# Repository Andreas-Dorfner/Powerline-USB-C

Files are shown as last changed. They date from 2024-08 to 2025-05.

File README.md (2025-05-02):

 # Powerline-USB-C
Powerline is a small 3HP Front Entry USB C Eurorack power supply.
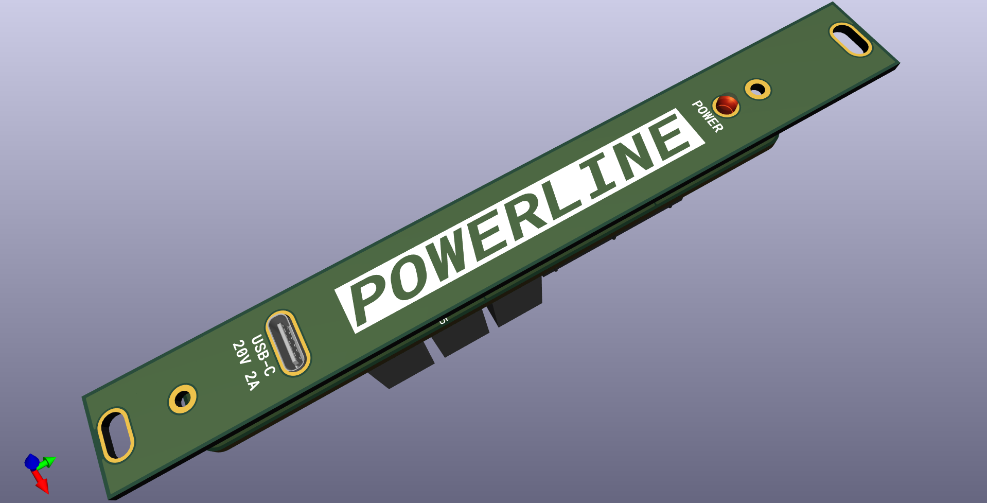
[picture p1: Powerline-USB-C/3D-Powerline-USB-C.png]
3D render

## Repository Layout
The Frontpanel and main PCB have a Kicad project with footprint and symbol libraries.
The main PCB also includes a 3D render of the Frontpanel as a Footprint
## Specs
- 12V 1000mA
- -12V 300mA
- 5V 1000mA
## Features
Powerline uses the cheap and readily available CH224k IC to get 20V over USB-C PD. The power brick should supply at least 2A of current at that voltage (40W Charger and above should be fine).
The 20V then gets regulated to a dual +/-12V and 5V supply by two N7812-1C and an N7805-1C and can be accessed by one 16-pin Power header. You can also omit the 5V rail and solder a 10pin header if none of your modules need 5V.
Powerline uses a single LED powered by the 12V rail to indicate power.
The PCBs are designed to jlcpcbs 2 Layer design capabilities to be compatible with most cheap PCB services.
## Parts List
The only difficult-to-source parts are the USB-C connector and regulator ICs. I got both from Digikey.
I also recommend sourcing the CH224k from a reputable supplier like LCSC to avoid broken parts.
You also need two M2 5mm standoffs and 4 M2 screws that fit the standoffs (max. 4mm) to assemble the Module.
Schematic
|Part Number|Value|Information|
|---|---|---|
|C1, C8|0805 1uF 50V X7R|Decoupling Capacitors|
|C2, C4, C6|1210 10uF 50V X7R|Input Cap for the regulator|
|C3, C5, C7|1210 22uF 25V X7R|Output cap for the regulator|
|D1|3mm LED|3mm radial LED with a nice color|
|J1|MC-802YC-H105|Female USB-C connector|
|J2|Power header|A 02x08 2.54mm pin spacing vertical through hole pin header|
|L1|1210 10uH|Look out for a rated current of above 600mA|
|R1|0603 5k1|Current limiting resistor for the LED: if it's too bright, pick a higher resistance|
|R2|0604 10k|VBUS sense resistor|
|U1|CH224K|The PD trigger IC|
|U2, U3|N7912-1C|+/-12V regulators|
|U4|N7805-1C|5V regulator|
|U5|HT7533-1|3.3V regulator|
|Standoffs|m2 5-7.5mm|You need 2 Standoffs and 4 screws to mount the Module to its front plate
## Build Guide
The PCB doesn't include any Thermal reliefs so that soldering can be tricky with a weak iron or small tip. I did everything with a 60W and 4mm Bevel Tip on a TS100 with extra Flux. You do not need additional equipment as the CH224K is solderable from the bottom. I used 7.5mm Standoffs, which protects the USB-C connector nicely. I would recommend soldering the USB-C connector last.

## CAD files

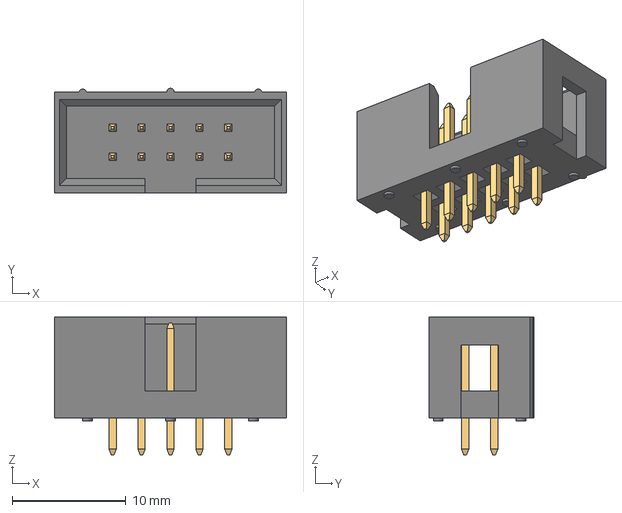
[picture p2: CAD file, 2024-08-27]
Powerline-USB-C/3D Models/Keye_10pin_Powerheader.stp
20.4 x 9.18 x 12.1 mm
6120xx21621_PIN x 10

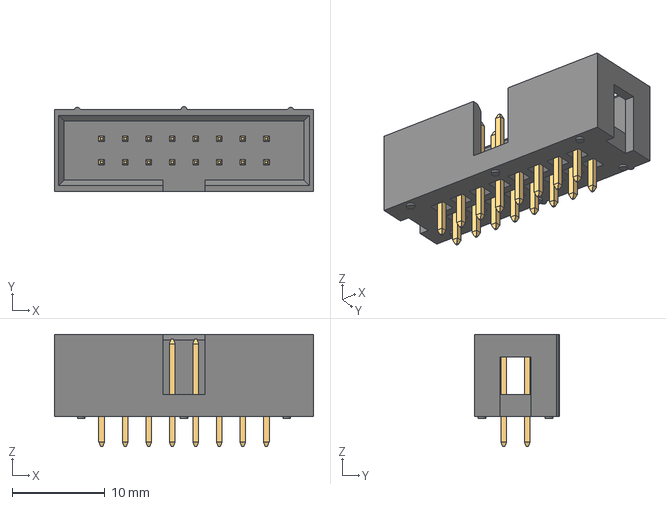
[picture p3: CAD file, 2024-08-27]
Powerline-USB-C/3D Models/Keyed_16pin_Powerheader.stp
28.0 x 9.18 x 12.1 mm
6120xx21621_PIN x 16

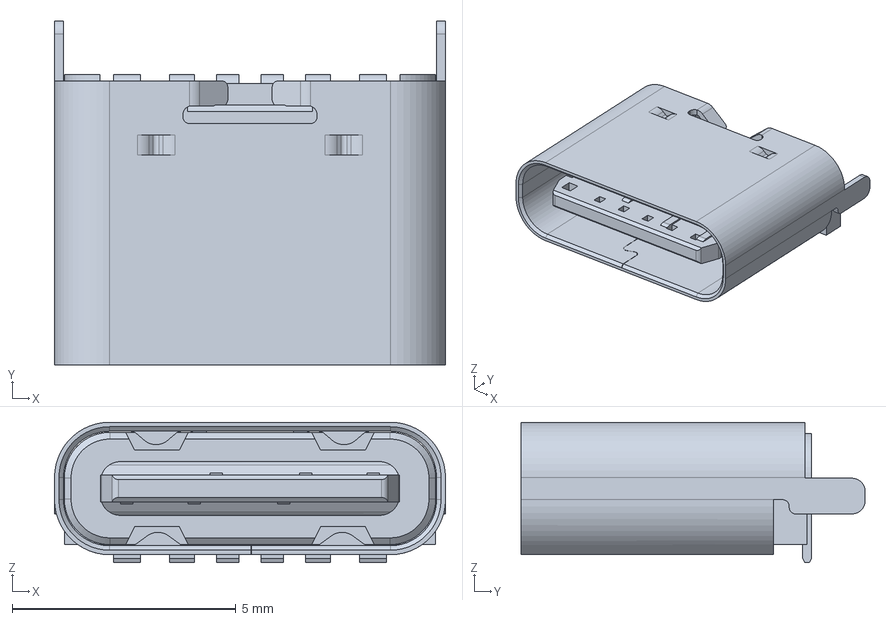
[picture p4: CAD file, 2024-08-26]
Powerline-USB-C/3D Models/USB-C.stp
8.74 x 7.70 x 3.14 mm

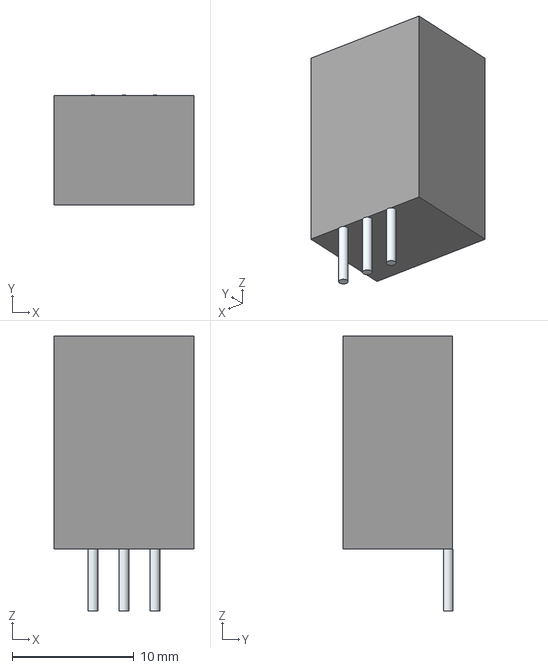
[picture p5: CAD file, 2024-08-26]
Powerline-USB-C/3D Models/N7803-1C.stp
11.5 x 9.08 x 22.6 mm
Leads

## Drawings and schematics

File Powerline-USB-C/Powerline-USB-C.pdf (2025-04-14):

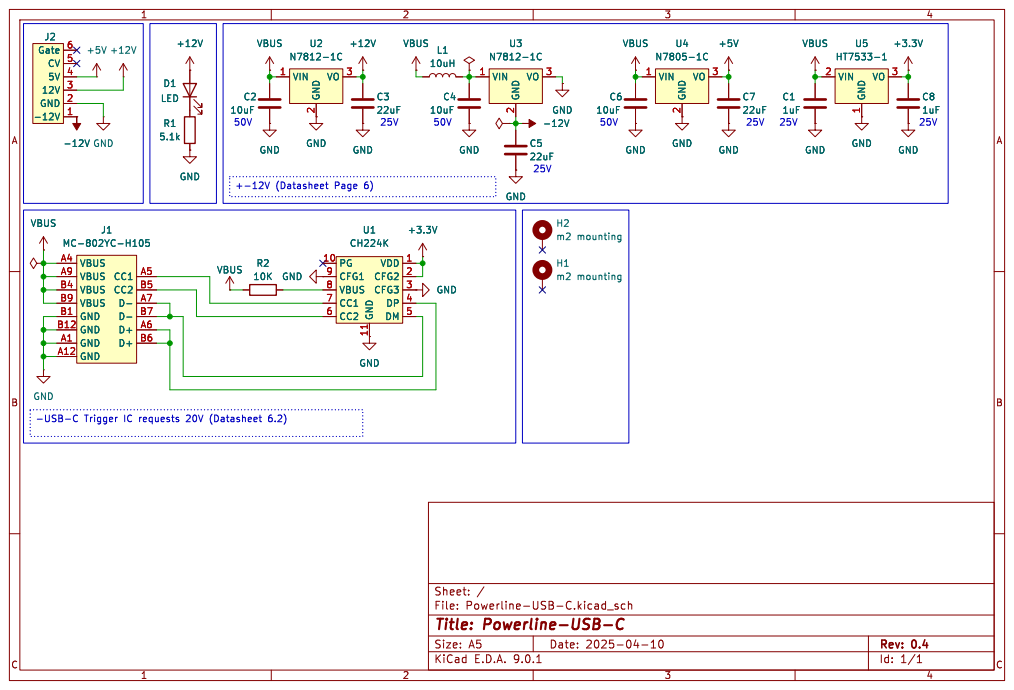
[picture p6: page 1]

2 VO 3 VBUS GND GND

Id: 1/1 Title: Powerline-USB-C

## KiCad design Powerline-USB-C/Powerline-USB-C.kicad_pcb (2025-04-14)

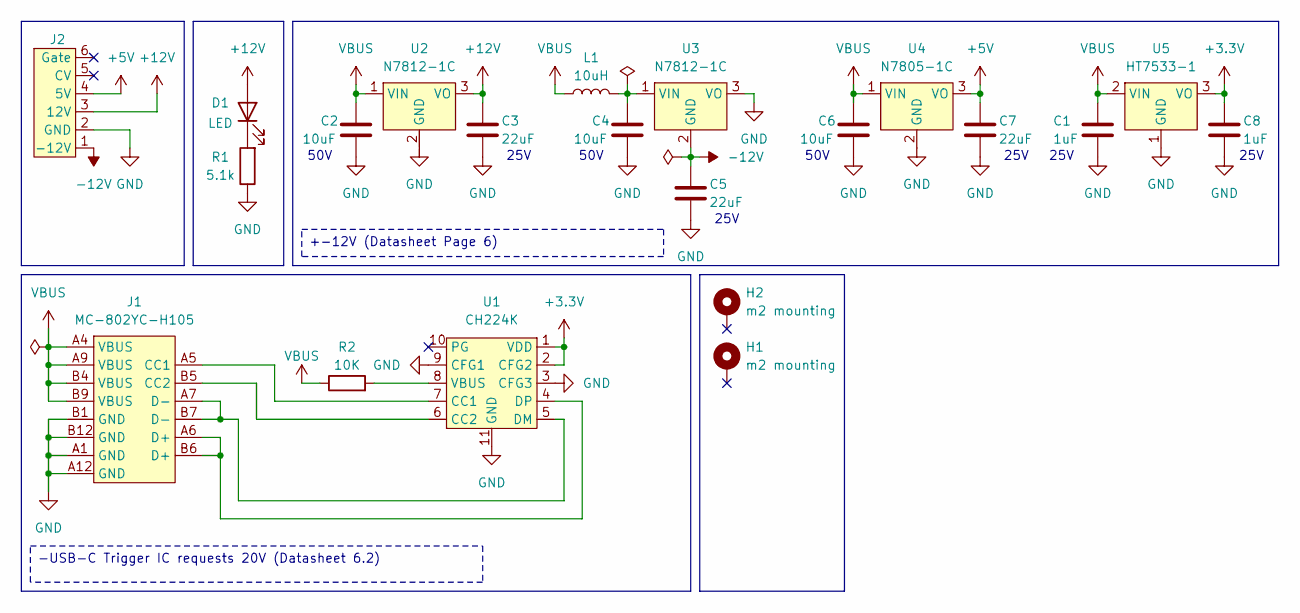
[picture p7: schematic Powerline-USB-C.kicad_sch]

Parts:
C1, C8: 1uF; C_0805_2012Metric
C2, C4, C6: 10uF; C_1210_3225Metric
C3, C5, C7: 22uF; C_1210_3225Metric
D1: LED; LED_D3.0mm
H1, H2: m2 mounting; MountingHole_2.2mm_M2_DIN965_Pad
J1: MC-802YC-H105; USB-C
J2: Keyed_16pin_Powerheader
L1: 10uH; L_1210_3225Metric
R1: 5.1k; C_0603_1608Metric
R2: 10K; R_0603_1608Metric
U1: CH224K; CH224k
U2, U3: N7812-1C
U4: N7805-1C; N7812-1C
U5: HT7533-1

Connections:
+3.3V: C8.1, U1.1 (VDD), U1.2 (CFG2), U5.3 (VO)
+5V: C7.1, J2.4 (5V), U4.3 (VO)
+12V: C3.1, D1.2 (A), J2.3 (12V), U2.3 (VO)
-12V: C5.1, J2.1 (-12V), U3.2 (GND)
GND: C1.2, C2.2, C3.2, C4.2, C5.2, C6.2, C7.2, C8.2, J1.A1 (GND), J1.A12 (GND), J1.B1 (GND), J1.B12 (GND), J2.2 (GND), R1.1, U1.3 (CFG3), U1.9 (CFG1), U1.11 (GND), U2.2 (GND), U3.3 (VO), U4.2 (GND), U5.1 (GND)
unnamed: D1.1 (K), R1.2
unnamed: J1.A5 (CC1), U1.7 (CC1)
unnamed: J1.B5 (CC2), U1.6 (CC2)
unnamed: J1.A7 (D-), J1.B7 (D-), U1.5 (DM)
unnamed: J1.A6 (D+), J1.B6 (D+), U1.4 (DP)
unnamed: R2.2, U1.8 (VBUS)
unnamed: C4.1, L1.2, U3.1 (VIN)
VBUS: C1.1, C2.1, C6.1, J1.A4 (VBUS), J1.A9 (VBUS), J1.B4 (VBUS), J1.B9 (VBUS), L1.1, R2.1, U2.1 (VIN), U4.1 (VIN), U5.2 (VIN)

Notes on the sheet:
25V
50V
-USB-C Trigger IC requests 20V (Datasheet 6.2)
+-12V (Datasheet Page 6)

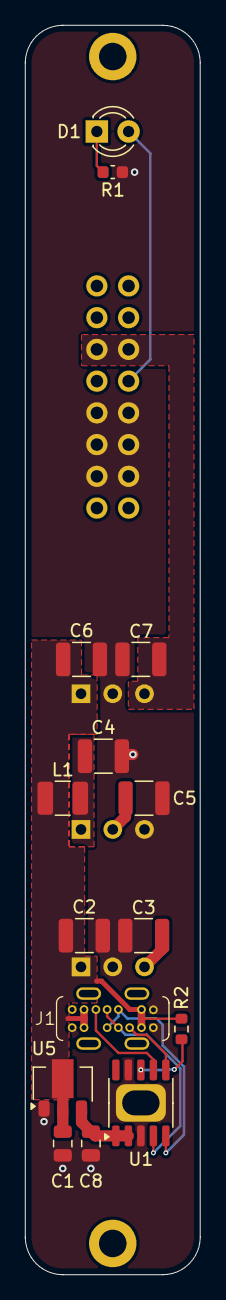
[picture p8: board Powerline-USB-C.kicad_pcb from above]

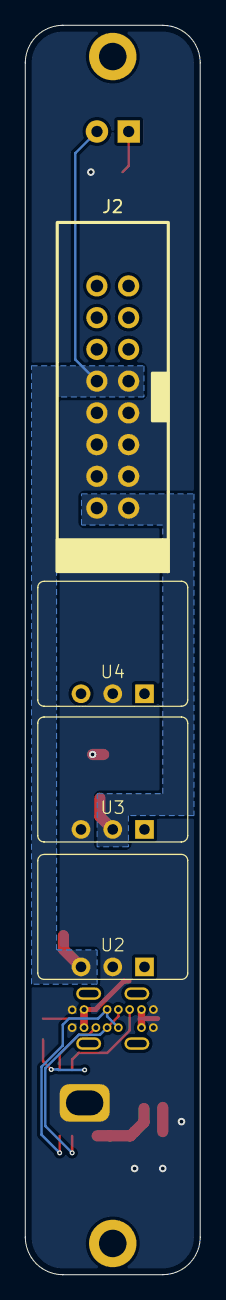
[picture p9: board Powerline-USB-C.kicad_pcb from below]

Board: 2 copper layers, 14.0 x 100.0 mm, 21 parts (4 on the bottom side), 13 nets.

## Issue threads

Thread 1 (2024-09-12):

wierd voltages

KeLaiFu, 2024-09-12:
I've built one of these and I am getting -12 and 5v on the header, but 4.9v on the +12. I checked the power coming from pin 1 on the IC, and its 1.3v (?) but 4.6v on the VBUS pin on the other side of R1.

I'm using meanwell DC blocks and ICs from LCSC and with such a small BOM, I am at a loss...

Any ideas?

Andreas-Dorfner, 2024-09-12:
I'm sorry your module isn't working as it should. The good thing is the voltages you measured mean that most of the module is ready to go. As for the rest:
The first thing to check is if the USB-C brick you are using supports 20V and the PD protocol.
If that is the case, that would indicate a problem with the USB-C trigger Circuit around the CH224K.
I haven't built the USB-C version of this module jet, so I can't confirm if the problem is in the schematic or your particular build. However, as you are using genuine parts, I highly suspect that the default implementation in the CH224k datasheet is faulty. As a quick fix, it will work for now if you supply the module with 20V through the USB-C port with a rigged cable (like a USB-C trigger cable) or a barrel Jack.
I will look through the USB-C trigger section again and update you if I find an error.

KeLaiFu, 2024-09-12:
OK, thanks for the update. it's good to know I havent broken it.

If you need me to test / try anything let me know.

stilltryin, 2024-12-21:
Hey,

i got kinda also into power trouble...get way off readings only 5V seems around 4.96, so cool...but i used bigger 7812-R2000 bricks and maybe there is the prob...happy for any update or suggests...

Andreas-Dorfner, 2024-12-21:
Sadly Uni has prevented me from tinkering with anything, so I am still not sure if that is the solution. But I would suggest injecting 20V into the USB-C port directly and not rely on the PD chip to work correctly. The rest of the circuit should work. I woll

KeLaiFu, 2025-04-08:
has this been forgotten? I still have a bag of DC blocks and caps waiting for this one...

Andreas-Dorfner, 2025-05-02:
The module is fixed and working for me. The problem was the datasheet of the CH224K; the example circuits don't work because you need 3.3V. I updated the repo. @KeLaiFu  @stilltryin

Closed 2025-05-02.

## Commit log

2024-08-26 Hardware commit
    Main PCB and Frontpanel Version 0.1
    [10pin_shrouded_smd_header.stp, N7803-1C.stp, Powerline-USB-C-Frontpanel.kicad_pcb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]
2024-08-27 minor hardware revision for main PCB
    -changed two 10pin headers for singele 16pin header
    -added 5V rail
    [10pin_shrouded_smd_header.stp, Keye_10pin_Powerheader.stp, Keyed_16pin_Powerheader.stp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]
2024-08-27 Added 3D renders and fixed file structure
    [Powerline-USB-C-Frontpanel.kicad_pcb, Powerline-USB-C-Frontpanel.kicad_sch, Powerline-USB-C.kicad_pcb]
2025-04-14 update to kicad9
    [Powerline-USB-C-Frontpanel.kicad_pcb, Powerline-USB-C-Frontpanel.kicad_sch, Powerline-USB-C.kicad_pcb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]
2025-04-14 Update to Kicad 9
    [Powerline-USB-C.kicad_pcb, Powerline-USB-C.kicad_sch]
